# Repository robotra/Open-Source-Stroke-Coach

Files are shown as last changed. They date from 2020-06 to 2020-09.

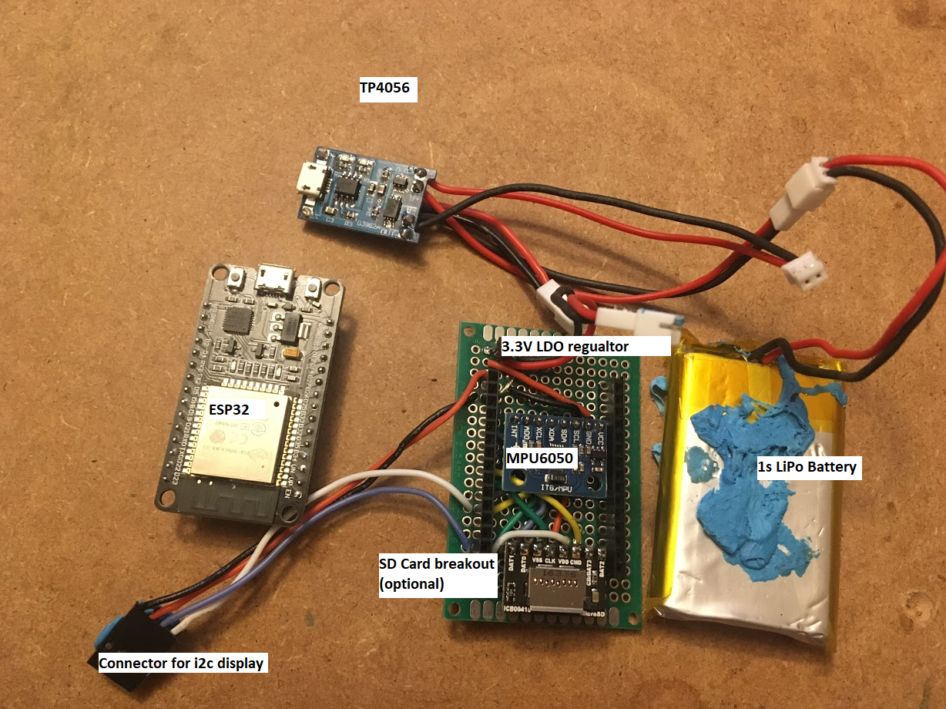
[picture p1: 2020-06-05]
DemoHardware.png

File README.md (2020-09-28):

# Open-Source-Stroke-Coach
This project aims to replicate some of the funcationality of the NK StrokeCoach, but at a much lower cost. 

Current hardware requirement: 
* ESP32 DOIT dev kit
* mpu6050 accelerometer
* I2C display

## Software
Stroke detection is based on the values from the accelerometer, smoothed by a low pass filter. This filtered data is then used to feed a peak detection algorithm, and time between peaks is used to calculate stroke rate. 

## To-do
* GPS
* Save to SD card as GPX file
* Then build out integration to the Strava API
* BLE HRM connection
* UI
* Minimize scope creep
* PCB

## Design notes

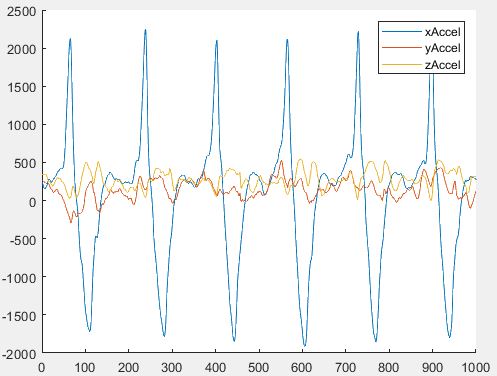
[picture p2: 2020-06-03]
Misc Data/Example of data collected.JPG

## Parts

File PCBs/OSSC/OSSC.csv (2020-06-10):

Source: | C:\Users\johnf\OneDrive\Rowing\Equipment\Open-Source-Stroke-Coach\PCBs\OSSC\OSSC.sch
Date: | 6/5/2020 9:22:55 AM
Tool: | Eeschema (5.1.5)-3
Generator: | C:\Program Files\KiCad\bin\scripting\plugins/bom_csv_grouped_by_value.py
Component Count: | 15
Individual Components:
Item | Qty | Reference(s) | Value | LibPart | Footprint | Datasheet
 |  | C1 | 0.1uF | Device:C | Capacitor_SMD:C_0402_1005Metric | ~
 |  | C2 | 2.2nF | Device:C | Capacitor_SMD:C_0402_1005Metric | ~
 |  | C3 | 0.1uF | Device:C | Capacitor_SMD:C_0402_1005Metric | ~
 |  | C4 | 2.3nF | Device:C | Capacitor_SMD:C_0402_1005Metric | ~
 |  | C5 | 0.1uF | Device:C | Capacitor_SMD:C_0402_1005Metric | ~
 |  | J1 | Conn_01x02_Female | Connector:Conn_01x02_Female | Connector_JST:JST_SH_SM02B-SRSS-TB_1x02-1MP_P1.00mm_Horizontal | ~
 |  | J2 | Conn_01x04 | Connector_Generic:Conn_01x04 | Connector_PinHeader_1.27mm:PinHeader_1x04_P1.27mm_Vertical | ~
 |  | J3 | Conn_01x01 | Connector_Generic:Conn_01x01 | Connector_PinHeader_1.00mm:PinHeader_1x01_P1.00mm_Vertical | ~
 |  | J4 | Conn_01x01 | Connector_Generic:Conn_01x01 | Connector_PinHeader_1.00mm:PinHeader_1x01_P1.00mm_Vertical | ~
 |  | R1 | 10k | OSSC-eagle-import:RESISTOR0402 | Resistor_SMD:R_0603_1608Metric_Pad1.05x0.95mm_HandSolder
 |  | R2 | 10k | Device:R | Resistor_SMD:R_0402_1005Metric | ~
 |  | R3 | 10k | Device:R | Resistor_SMD:R_0402_1005Metric | ~
 |  | U1 | MCP1700-3302E_SOT23 | Regulator_Linear:MCP1700-3302E_SOT23 | Package_TO_SOT_SMD:SOT-23 | http://ww1.microchip.com/downloads/en/DeviceDoc/20001826D.pdf
 |  | U2 | ESP32-WROOM-32 | RF_Module:ESP32-WROOM-32 | RF_Module:ESP32-WROOM-32 | https://www.espressif.com/sites/default/files/documentation/esp32-wroom-32_datasheet_en.pdf
 |  | U3 | MPU-6050 | Sensor_Motion:MPU-6050 | Sensor_Motion:InvenSense_QFN-24_4x4mm_P0.5mm | https://store.invensense.com/datasheets/invensense/MPU-6050_DataSheet_V3%204.pdf
Collated Components:
Item | Qty | Reference(s) | Value | LibPart | Footprint | Datasheet
1 | 3 | C1, C3, C5 | 0.1uF | Device:C | Capacitor_SMD:C_0402_1005Metric | ~
2 | 1 | C2 | 2.2nF | Device:C | Capacitor_SMD:C_0402_1005Metric | ~
3 | 1 | C4 | 2.3nF | Device:C | Capacitor_SMD:C_0402_1005Metric | ~
4 | 1 | J1 | Conn_01x02_Female | Connector:Conn_01x02_Female | Connector_JST:JST_SH_SM02B-SRSS-TB_1x02-1MP_P1.00mm_Horizontal | ~
5 | 1 | J2 | Conn_01x04 | Connector_Generic:Conn_01x04 | Connector_PinHeader_1.27mm:PinHeader_1x04_P1.27mm_Vertical | ~
6 | 2 | J3, J4 | Conn_01x01 | Connector_Generic:Conn_01x01 | Connector_PinHeader_1.00mm:PinHeader_1x01_P1.00mm_Vertical | ~
7 | 1 | R1 | 10k | OSSC-eagle-import:RESISTOR0402 | Resistor_SMD:R_0603_1608Metric_Pad1.05x0.95mm_HandSolder
8 | 2 | R2, R3 | 10k | Device:R | Resistor_SMD:R_0402_1005Metric | ~
9 | 1 | U1 | MCP1700-3302E_SOT23 | Regulator_Linear:MCP1700-3302E_SOT23 | Package_TO_SOT_SMD:SOT-23 | http://ww1.microchip.com/downloads/en/DeviceDoc/20001826D.pdf
10 | 1 | U2 | ESP32-WROOM-32 | RF_Module:ESP32-WROOM-32 | RF_Module:ESP32-WROOM-32 | https://www.espressif.com/sites/default/files/documentation/esp32-wroom-32_datasheet_en.pdf
11 | 1 | U3 | MPU-6050 | Sensor_Motion:MPU-6050 | Sensor_Motion:InvenSense_QFN-24_4x4mm_P0.5mm | https://store.invensense.com/datasheets/invensense/MPU-6050_DataSheet_V3%204.pdf

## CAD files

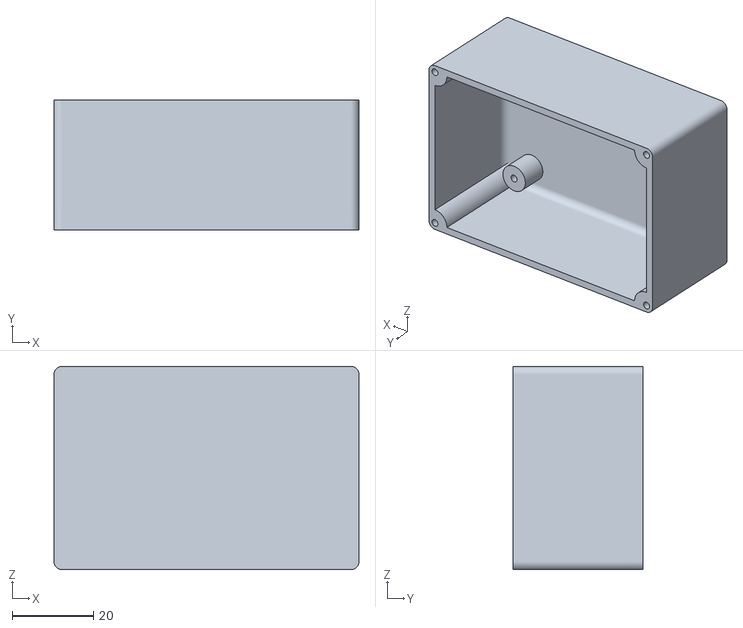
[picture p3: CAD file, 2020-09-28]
CAD/Enclosure.stl
75.0 x 32.0 x 50.0

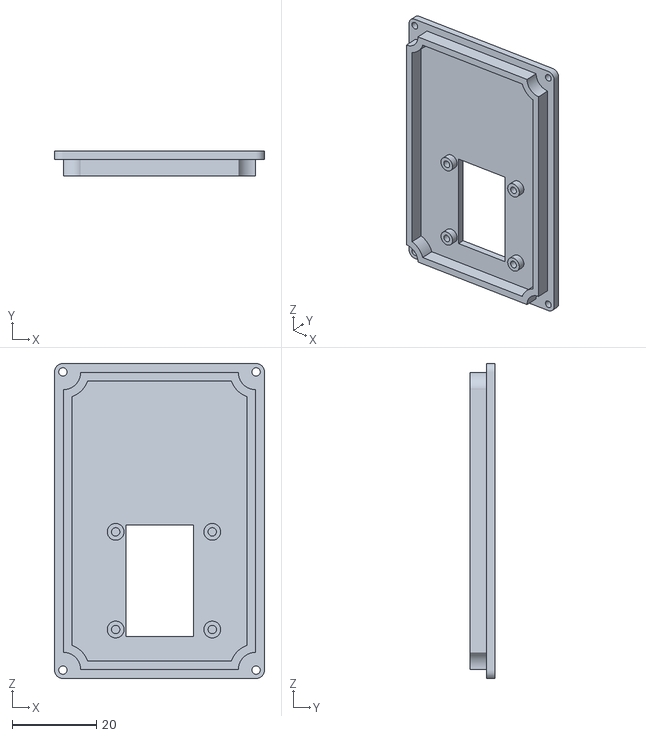
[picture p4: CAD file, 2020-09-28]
CAD/Enclosure Lid.stl
50.0 x 6.00 x 75.0

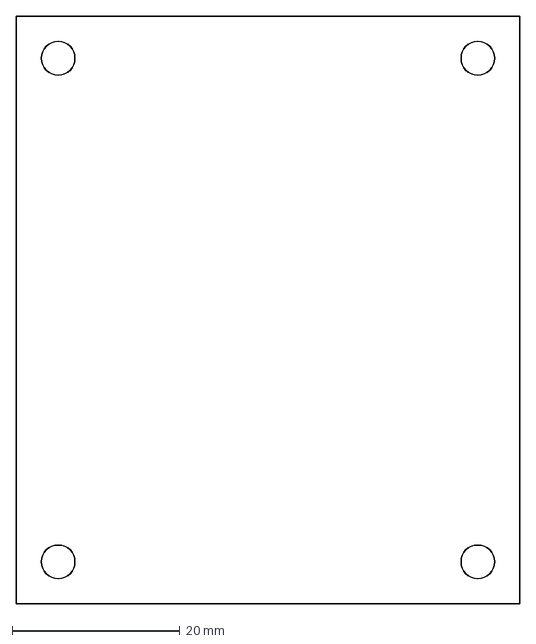
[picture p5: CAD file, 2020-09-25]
CAD/face.dxf
60.0 x 70.0 mm

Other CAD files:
CAD/Enclosure Lid.ipt
CAD/Enclosure.ipt
CAD/OldVersions/Enclosure Lid.0006.ipt
CAD/OldVersions/Enclosure.0006.ipt

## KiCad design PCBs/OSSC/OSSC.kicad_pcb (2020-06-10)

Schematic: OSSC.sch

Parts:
C1, C3, C5: 0.1uF; C_0402_1005Metric
C2: 2.2nF; C_0402_1005Metric
C4: 2.3nF; C_0402_1005Metric
J1: Conn_01x02_Female; JST_SH_SM02B-SRSS-TB_1x02-1MP_P1.00mm_Horizontal
J2: Conn_01x04; PinHeader_1x04_P1.27mm_Vertical
J3, J4: Conn_01x01; PinHeader_1x01_P1.00mm_Vertical
R1: 10k; R_0603_1608Metric_Pad1.05x0.95mm_HandSolder
R2, R3: 10k; R_0402_1005Metric
U1: MCP1700-3302E_SOT23; SOT-23
U2: ESP32-WROOM-32
U3: MPU-6050; InvenSense_QFN-24_4x4mm_P0.5mm

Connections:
+BATT: J1.2, U1.3 (VI)
GND: C1.1, C3.2, C4.2, C5.1, J1.1, J2.2, U1.1 (GND), U2.1 (GND), U2.15 (GND), U2.38 (GND), U2.39 (GND), U3.1 (CLKIN), U3.9 (AD0), U3.11 (FSYNC), U3.18 (GND)
I2C-SCL: J2.3, R3.2, U2.36 (IO22), U3.23 (SCL)
I2C-SDA: J2.4, R2.2, U2.33 (IO21), U3.24 (SDA)
MPU-6050-INT: U2.23 (IO15), U3.12 (INT)
unnamed: C1.2, R1.1, U2.3 (EN)
unnamed: C2.1, U3.8 (VDDIO)
unnamed: C4.1, U3.20 (CPOUT)
unnamed: C5.2, U3.10 (REGOUT)
unnamed: J3.1, U2.35 (TXD0/IO1)
unnamed: J4.1, U2.34 (RXD0/IO3)
VCC-3.3V: C2.2, C3.1, J2.1, R1.2, R2.1, R3.1, U1.2 (VO), U2.2 (VDD), U3.13 (VDD)

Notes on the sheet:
I2C-Connector for Display

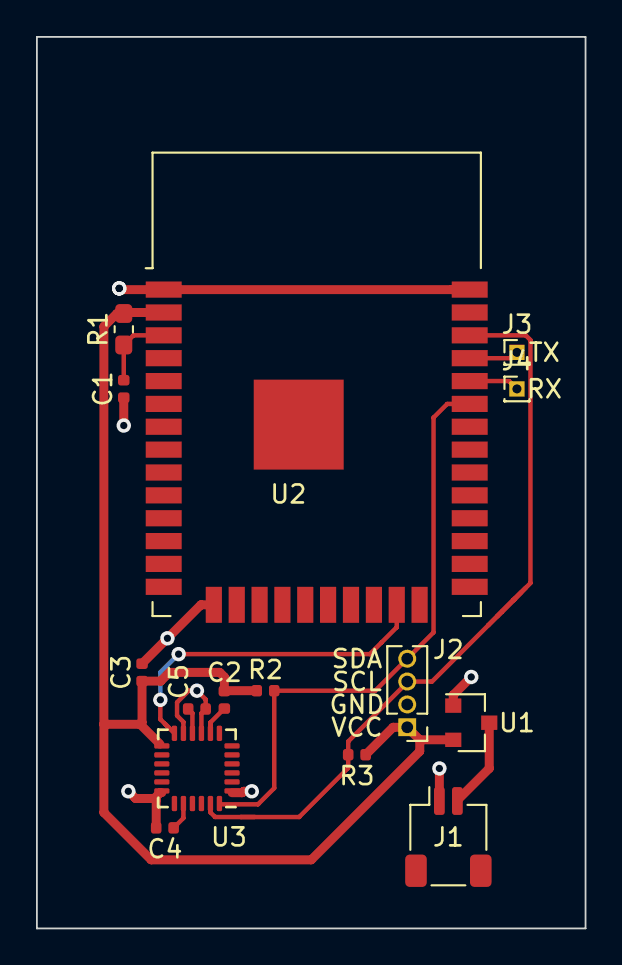
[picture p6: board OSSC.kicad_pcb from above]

Board: 2 copper layers, 30.5 x 49.5 mm, 15 parts (0 on the bottom side), 12 nets.

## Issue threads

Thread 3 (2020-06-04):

Schematic change

Librix8, 2020-06-04:
Why did you put in those two Capacitors between the IC and Gound?

And you will need to power the Enable pin(Datasheet):

"To ensure the power supply to the ESP32 chip during power-up, it is advised to add an RC delay circuit at the EN pin. The recommended setting for the RC delay circuit is usually
R = 10 kΩ and C = 0.1 µF. However, specific parameters should be adjusted based on the power-up timing of the module and the power-up and reset sequence timing of the chip.
For ESP32’s power-up and reset sequence timing diagram, please refer to Section Power Scheme in ESP32 Datasheet"

robotra, 2020-06-04:
Thank you! I have zero training in EE or adjacent fields so am very much winging it.

Closed 2020-06-04.

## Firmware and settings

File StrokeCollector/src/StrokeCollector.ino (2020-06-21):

/* Building an ESP32 Based stroke coach, built on JRowbergs I2C library, for 6050 acclerometer interfacing
   https://github.com/jrowberg/i2cdevlib
   An arduino based implementation a low pass filter, from Bill Williams
   https://github.com/Billwilliams1952/Arduino-Cascadable-Low-Pass-Filter
   With another version for the addition of an Adafruit Ultimate GPS module
   https://www.adafruit.com/product/746


*/

#include "I2Cdev.h"
#include "MPU6050_6Axis_MotionApps20.h"
#include "Wire.h"
#include <SPI.h>
#include <SD.h>
#include <SoftwareSerial.h>
#include <Lpf.h>
#include "SSD1306Wire.h" // legacy: #include "SSD1306.h"
#include <CircularBuffer.h>
#include "BLEDevice.h"

//initialize MPU object
MPU6050 mpu(0x68);

//ESP32 board constants
#define INTERRUPT_PIN 15 // using pin 15 on ESP32 because any pin can be an interrupt
#define LED_PIN 2        // (ESP32 is 2, Arduino is 13, Teensy is 11, Teensy++ is 6)
bool blinkState = false;

// Set the variables for SD Cards
//FInal version probably wont need an SD card with the ESP32 due to the large enough internal memory (maybe)
#define cardSelect 5 //SD Card pin select
File logfile;
char filename[15];

// MPU control/status vars
bool dmpReady = false;  // set true if DMP init was successful
uint8_t mpuIntStatus;   // holds actual interrupt status byte from MPU
uint8_t devStatus;      // return status after each device operation (0 = success, !0 = error)
uint16_t packetSize;    // expected DMP packet size (default is 42 bytes)
uint16_t fifoCount;     // count of all bytes currently in FIFO
uint8_t fifoBuffer[64]; // FIFO storage buffer

// Orientation/motion vars
Quaternion q;        // [w, x, y, z]         quaternion container
VectorInt16 aa;      // [x, y, z]            accel sensor measurements
VectorInt16 aaReal;  // [x, y, z]            gravity-free accel sensor measurements
VectorInt16 aaWorld; // [x, y, z]            world-frame accel sensor measurements
VectorFloat gravity; // [x, y, z]            gravity vector

#define BANDWIDTH_HZ 1.0        // 3-dB bandwidth of the filter
#define SAMPLE_TIME_SEC 1e-2    // How often are we upodating the loop? The LPF tracks the sample time internally
#define SIGNAL_FREQUENCY_HZ 0.3 // Our test input signal frequency

LPF lpfx(BANDWIDTH_HZ, IS_BANDWIDTH_HZ);
LPF lpfy(BANDWIDTH_HZ, IS_BANDWIDTH_HZ);
LPF lpfz(BANDWIDTH_HZ, IS_BANDWIDTH_HZ);

SSD1306Wire display(0x3c, SDA, SCL); // ADDRESS, SDA, SCL  -  SDA and SCL usually populate automatically based on your board's pins_arduino.h
int rRate = 0;
String dAx = "";
String dAy = "";
String dAz = "";
String dAv = "";
String dAr = "";

CircularBuffer<int, 1000> aBuffer;
CircularBuffer<int, 100> mBuffer;
CircularBuffer<int, 1000> rBuffer;
float max_v;
float pTime;
float cTime;
int HRVal = 0;
#define SEEK_TRKPT_BACKWARDS -2
#define GPX_EPILOGUE "\t</trkseg></trk>\n</gpx>\n"
#define LATLON_PREC 6


// ================================================================
// ===               INTERRUPT DETECTION ROUTINE                ===
// ================================================================

volatile bool mpuInterrupt = false; // indicates whether MPU interrupt pin has gone high

void dmpDataReady()
{
  mpuInterrupt = true;
}

// ================================================================
// ===                      INITIAL SETUP                       ===
// ================================================================

void setup()
{
  // join I2C bus (I2Cdev library doesn't do this automatically)
  Wire.begin(21, 22, 600000);

  pinMode(13, OUTPUT);

  Serial.begin(115200);

  // initialize device
  Serial.println(F("Initializing I2C devices..."));
  delay(500);
  mpu.initialize();
  delay(500);
  devStatus = mpu.dmpInitialize();
  delay(500);

  // supply your own gyro offsets here, scaled for min sensitivity
  mpu.setXGyroOffset(79);
  mpu.setYGyroOffset(65);
  mpu.setZGyroOffset(19);
  mpu.setXAccelOffset(-3011);
  mpu.setYAccelOffset(-1833);
  mpu.setZAccelOffset(1030); // 1688 factory default for my test chip

  // make sure it worked (returns 0 if so)
  if (devStatus == 0)
  {
    // Calibration Time: generate offsets and calibrate our MPU6050
    mpu.CalibrateAccel(6);
    mpu.CalibrateGyro(6);
    mpu.PrintActiveOffsets();
    mpu.setDMPEnabled(true);

    //Set sample collection rate to 100Hz
    mpu.setRate(9);

    pinMode(INTERRUPT_PIN, INPUT);
    attachInterrupt(INTERRUPT_PIN, dmpDataReady, RISING);
    mpuIntStatus = mpu.getIntStatus();

    // set our DMP Ready flag so the main loop() function knows it's okay to use it
    Serial.println(F("DMP ready! Waiting for first interrupt..."));
    dmpReady = true;

    // get expected DMP packet size for later comparison
    packetSize = mpu.dmpGetFIFOPacketSize();
  }
  else
  {
    // ERROR!
    // 1 = initial memory load failed
    // 2 = DMP configuration updates failed
    // (if it's going to break, usually the code will be 1)
    Serial.print(F("DMP Initialization failed (code "));
    Serial.print(devStatus);
    Serial.println(F(")"));
  }

  // configure LED for output
  pinMode(LED_PIN, OUTPUT);

  pinMode(8, OUTPUT);
  Serial.println("Ready!");

  if (!SD.begin(cardSelect))
  {
    Serial.println("Card init. failed!");
    digitalWrite(LED_PIN, HIGH);
  }
  strcpy(filename, "/ANALOG00.TXT");
  for (uint8_t i = 0; i < 100; i++)
  {
    filename[7] = '0' + i / 10;
    filename[8] = '0' + i % 10;
    // create if does not exist, do not open existing, write, sync after write
    if (!SD.exists(filename))
    {
      break;
    }
  }

  File logfile = SD.open(filename, FILE_WRITE);
  if (!logfile)
  {
    Serial.print("Couldnt create ");
    Serial.println(filename);
  }
  logfile.close();
  Serial.print("Writing to ");
  Serial.println(filename);

  //display initialization
  display.init();
  display.flipScreenVertically();
  display.setFont(ArialMT_Plain_24);
  logfile = SD.open(filename, FILE_APPEND);
  logfile.print("end o file");
  logfile.close();
}

// ================================================================
// ===                    MAIN PROGRAM LOOP                     ===
// ================================================================

void loop()
{
  // if programming failed, don't try to do anything
  if (!dmpReady)
    return;
  // read a packet from FIFO
  if (mpu.dmpGetCurrentFIFOPacket(fifoBuffer))
  { // Get the Latest packet
    detachInterrupt(INTERRUPT_PIN);
    mpu.dmpGetQuaternion(&q, fifoBuffer);
    mpu.dmpGetAccel(&aa, fifoBuffer);
    mpu.dmpGetGravity(&gravity, &q);
    mpu.dmpGetLinearAccel(&aaReal, &aa, &gravity);

    float aaX = lpfx.NextValue(aaReal.x);
    float aaY = lpfy.NextValue(aaReal.y);
    float aaZ = lpfz.NextValue(aaReal.z);

    float aVal = aaY + aaZ;
    //Add filtered accel value to head of buffer
    aBuffer.unshift(aVal);

    //every loop set max accel to zero
    max_v = 1;

    //go through the first 100 elements of the Accel buffer
    for (int i = 0; i < 100; i++)
    {
      // if the accel value in i is the biggest
      if (aBuffer[i] >= max_v)
      {
        //change max_v
        max_v = aBuffer[i];
      }
      //add max value to the max value buffer
      mBuffer.unshift(max_v);
    }

    float vAvg = 1.0;

    //calcualte average of the previous [size of buffer] maximum values
    for (int i = 0; i < 100; i++)
    {
      vAvg += mBuffer[i];
    }
    vAvg = vAvg / 100;

    // if the current acceleration value is greater than 90% of avereage of the previous 100 max values
    // and it has been at least a second since the last measurement,
    if (aVal > 0.9 * vAvg && millis() - pTime > 1000)
    {
      //add rate based on peak to peak to the rate measurement buffer
      rBuffer.unshift(1 / ((millis() - pTime) / 60000));
      //reset previous time
      pTime = millis();
    }

    Serial.print(millis());
    Serial.print(",");
    Serial.print(lpfx.NextValue(aaReal.x));
    Serial.print(",");
    Serial.print(lpfy.NextValue(aaReal.y));
    Serial.print(",");
    Serial.print(lpfz.NextValue(aaReal.z));
    Serial.print(",");
    Serial.print(rBuffer[0]);
    // Serial.print(",");
    // Serial.print(HRVal);
    Serial.println(",");

    //write values to file every 3 seconds
    if (millis() - rRate >= 3000)
    {
      dAx = String(lpfx.NextValue(aaReal.x));
      dAy = String(lpfy.NextValue(aaReal.y));
      dAz = String(lpfz.NextValue(aaReal.z));
      dAv = String(sqrt(aaX * aaX + aaY * aaY + aaZ * aaZ));
      dAr = String((rBuffer[0] + rBuffer[1] + rBuffer[2]) / 3);
      logfile = SD.open(filename, FILE_APPEND);
      logfile.seek((logfile.size() - 9));
      logfile.print(dAx);
      logfile.print(",");
      logfile.print(dAy);
      logfile.print(",");
      logfile.print(dAr);
      logfile.println(",");
      logfile.close();
      rRate = millis();
    }

    display.clear();

    display.drawString(0, 0, "Time:");
    display.drawString(60, 0, String(millis() / 1000.0));

    display.drawString(0, 22, "Rate:");
    display.drawString(60, 22, dAr);

    display.drawString(0, 44, "HR:");
    //display.drawString(60, 44, String(HRVal));

    display.display(); // Show initial text
    // blink LED to indicate activity
    blinkState = !blinkState;
    digitalWrite(LED_PIN, blinkState);
    mpu.resetFIFO();
    attachInterrupt(INTERRUPT_PIN, dmpDataReady, RISING);
  }
}

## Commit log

2019-08-06 Arduino code
    [LOGGER00.CSV, LOGGER01.CSV, LOGGER02.CSV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]
2019-08-20 millis tracking
2019-08-23 Switch to neoGPS
2020-05-27 esp32 read data from accelerometer and write to SD card sketch added
    [192213.xlsx]
2020-05-28 commit to greate ESP32 based logger in order to get some test accelerometer data in order to genreeate a stroke detection algorithm.
2020-05-28 increase sample rate
2020-05-28 add dummy data file
    [Dummy data.csv]
2020-05-29 Redefining things for ESP32
2020-05-29 cleaning up folder
    [192213.xlsx, LOGGER00.CSV, LOGGER01.CSV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]
2020-05-29 modifications for detatching interrupt during write to SD in order to hopefully improve logging
2020-05-29 Updates and placement of missing semicolons
    [esp32-6050-datacollector.ino]
2020-05-29 set sample rate to 100Hz
2020-05-30 Addition of low pass filter to -nogps test code. Seems to be promising.
    [FourierAnalysisAndButterworthFilter.xlsx]
2020-06-02 pcb + oled
    [OSSC.kicad_pcb, OSSC.sch]
2020-06-02 added erg handle dummy data that was collected after the LPF
    [ErgHandleDummyData.csv]
2020-06-03 addition of data captured from a rowing in the 1x
    [1xDummyData.csv]
2020-06-04 Add files via upload
    NEW KICAD PCB-Layout
    [OSSC.kicad_pcb]
2020-06-04 Schematic Change
    -Removed 2 Cap between IC-Ground to Ground
    -Added Power-Up Delay-Circuit for ESP
    -Added Filter-Cap for MPU
    [OSSC.kicad_pcb, OSSC.sch]
2020-06-05 Added Components
    Added Components for MPU-6050
    Added I2C-Connector for Display
    Added two Pins for Programming
    [OSSC.kicad_pcb, OSSC.sch]
2020-06-10 creation of PlatformIO related files
    [OSSC-B_Cu.gbr, OSSC-B_Mask.gbr, OSSC-B_Paste.gbr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]
2020-09-17 Update to folder organization and renaming of files
    [1xDummyData.csv, Dummy data.csv, ErgHandleDummyData.csv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]
2020-09-21 Addition of sleep timer using LPF
2020-09-25 added some power control and worked on enclosure for the device.
    [Enclosure Lid.0003.ipt, Enclosure Lid.ipt, Enclosure Lid.stl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]
2020-09-28 update of cad files
    [Enclosure Lid.0003.ipt, Enclosure Lid.0006.ipt, Enclosure Lid.ipt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]
